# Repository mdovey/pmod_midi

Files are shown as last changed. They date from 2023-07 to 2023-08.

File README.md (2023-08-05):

# pmod_midi
#### PMOD Adapter for the CME Widi Core BLE MIDI module

 

Kicad files for a PCB adapter board/shield to allow the [CME Widi Core module](https://www.cme-pro.com/widi-core/) to be connected to development boards which use the [Digilent PMOD connector](https://digilent.com/shop/about-system-boards-and-components/).

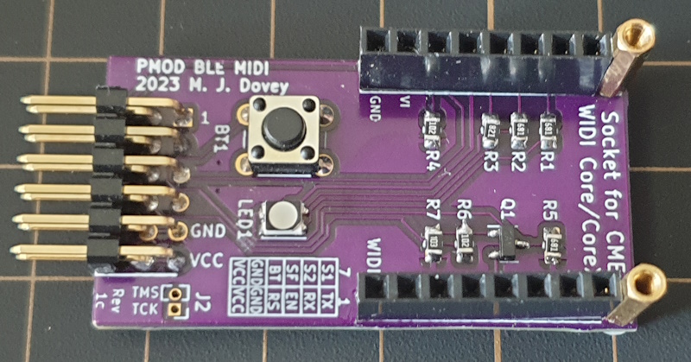
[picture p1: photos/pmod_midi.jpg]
PMOD_MIDI Photograph


| PMOD Pin | Core Pin | Notes |
| --- | --- | --- |
| 1 | 1 (TX) | Connects directly to Widi Core TX pin for MIDI over UART |
| 2 | 11 (RX)  | Connects directly to Widi Core RX pin for MIDI over UART |
| 3 | 6 (ON) | Connects to Widi Core ON pin via pull down resistor. Active high to enable the Widi Core module. |
| 4 | 12 (RS)  | Connects to Widi Core RS pin. Active low reset. |
| 7 | 16 (S1)  | Connects to Widi Core S1 pin. Bluetooth connection status (0 = Not connected, 1 = Connected). |
| 8 | 15 (S2)  | Connects to Widi Core C2 pin. Bluetooth role (0 = peripheral, 1 = central) |
| 9 | 13 (SF)  | Connects to Widi Core SF pin. Baud rate (0 = 31.25 Kb/s, 1 = 100 Kb/s). Requires reset cycle to execute change. |
| 10 | 14 (BT)  | If 1, shorts Widi Core BT pin to ground - simulating button press. |

The board also has a push button which shorts Widi Core pin 14 (BT) to ground (for factory reset and bluetooth role change), and an RGB LED, powered by Widi Core pins 2 (LB), 3(LG), 4 (LR) and 5(V3), for status information (see [CME Widi Core datasheet](https://www.cme-pro.com/wp-content/uploads/2022/10/widiCore-Doc-v1.3.pdf), page 9). An optional 0.5 inch pitch header can provide access to the Widi Core pins 9 (TMS) and 10 (TCK)

The [BOM](./kicad/pmod_midi_bom.md) includes sockets to allow the CME Widi Core (or the Core N/XN with suitable headers) to be inserted and removed. Alternatively the Core N/XN can be hard soldered for example using 0.1 inch pitch header pins.

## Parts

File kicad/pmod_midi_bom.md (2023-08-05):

# pmod_midi.kicad_sch BOM

05/08/2023 12:28:57

Generated from schematic by Eeschema 7.0.6

**Component Count:** 20

| Refs | Qty | Component | Description | Manufacturer | MPN | Notes |
| ----- | --- | ---- | --- | ---- | ---- | ---- |
| BT1 | 1 | SW_Push | Push button switch, generic, two pins | CUI | [TS02-66-60-BK-160-LCR-D](https://www.mouser.co.uk/datasheet/2/670/ts02-2586188.pdf) | 6mm momentarily closed tactile button switch |
| H1, H2 | 2 | MountingHole_Pad | Mounting Hole with connection | Würth Elektronik | [970100244](https://www.we-online.com/components/products/datasheet/970100244.pdf) | Optional: 10mm M2 female to female standoff spacer,  |
| J1 | 1 | PMOD (12 Pin) | Digilent 12 Pin PMOD Connector | Samtec | [TSW-106-08-L-D-RA](https://suddendocs.samtec.com/catalog_english/tsw_th.pdf) | 2x6 0.1 Inch pitch right-angle pin header |
| J2 | 1 | Conn_01x02_Pin | Generic connector, single row, 01x02, script generated | Mill-Max | [852-10-002-10-001000](https://www.mill-max.com/catalog/download/2017-11:034.pdf) | Optional: 1x2 0.05 Inch pitch pin header |
| J3 | 1 | CME_Widi_Core_1-8 | CME Widi Core - Pins 1 - 8 | Samtec | [SSW-108-01-L-S](https://suddendocs.samtec.com/catalog_english/ssw_th.pdf) | 1x8 0.1 Inch pitch pin header socket; . For insertion of pins 1-8 of [CME Widi Core module](https://www.cme-pro.com/wp-content/uploads/2022/10/widiCore-Doc-v1.3.pdf). |
| J4 | 1 | CME_Widi_Core_9-16 | CME Widi Core - Pins 9 - 16 | Samtec | [SSW-108-01-L-S](https://suddendocs.samtec.com/catalog_english/ssw_th.pdf) | 1x8 0.1 Inch pitch pin header socket; . For insertion of pins 9-16 of [CME Widi Core module](https://www.cme-pro.com/wp-content/uploads/2022/10/widiCore-Doc-v1.3.pdf). |
| LED1 | 1 | LED_ABRG | RGB LED, anode/blue/red/green | Würth Elektronik | [150141M173100](https://www.we-online.com/components/products/datasheet/150141M173100.pdf) | 3528 SMD Common Anode RGB LED (Parity Pin 1 - Red Cathode) |
| Q1 | 1 | Q_NPN_BCE | NPN transistor, base/collector/emitter | STMicroelectronics | [2STR2160](https://www.st.com/resource/en/datasheet/2str2160.pdf) | SOT-23 3 SMD NPN Transistor (Pin order: BCE) |
| R1, R2, R5 | 3 | 680 | Resistor |  | 680 ohm 0805 SMD Resistor |  |
| R3 | 1 | 820 | Resistor |  | 820 ohm 0805 SMD Resistor |  |
| R4, R6 | 2 | 1k | Resistor |  | 1k ohm 0805 SMD Resistor |  |
| R7 | 1 | 10k | Resistor |  | 10k ohm 0805 SMD Resistor |  |
| U1–4 | 4 | M2 Nylon Machine Screw | Machine Screw | Essentra | [50M020040D004](https://www.essentracomponents.com/en-us/p/nylon-cheese-head-screws/50m020040d004) | Optional: M2 4mm nylon pan head machine screw |

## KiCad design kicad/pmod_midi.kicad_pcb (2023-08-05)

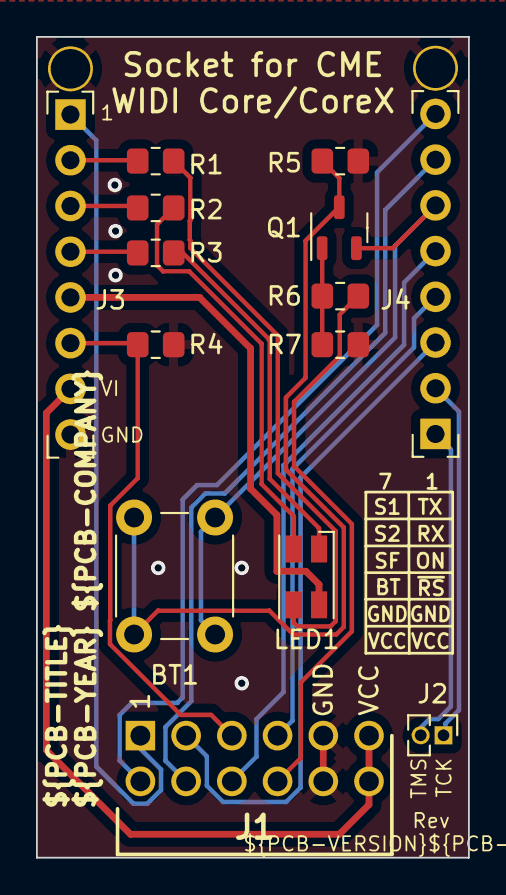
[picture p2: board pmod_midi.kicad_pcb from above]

Board: 2 copper layers, 24.0 x 45.6 mm, 16 parts (0 on the bottom side), 22 nets.

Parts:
BT1: SW_Push; SW_PUSH_6mm
H1, H2: MountingHole_Pad; Standoff Spacer
J1: PMOD (12 Pin)
J2: Conn_01x02_Pin; PinHeader_1x02_P1.27mm_Vertical
J3: CME_Widi_Core_1-8; CME Widi Core Socket Pins 1 - 8
J4: CME_Widi_Core_9-16; CME Widi Core Socket Pins 9 - 16
LED1: LED_ABRG; LED_RGB_Wuerth-PLCC4_3.2x2.8mm_150141M173100
Q1: Q_NPN_BCE; SOT-23-3
R1, R2, R5: 680; R_0805_2012Metric_Pad1.20x1.40mm_HandSolder
R3: 820; R_0805_2012Metric_Pad1.20x1.40mm_HandSolder
R4, R6: 1k; R_0805_2012Metric_Pad1.20x1.40mm_HandSolder
R7: 10k; R_0805_2012Metric_Pad1.20x1.40mm_HandSolder

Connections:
/3.3V: J1.6 (VCC), J1.12 (VCC), J3.7 (VI)
/BLUE: LED1.2 (BK), R1.1
/BT: J1.10, R6.2
/BT*: Q1.1 (B), R6.1, R7.1
/GND: H1.1, H2.1, J1.5 (GND), J1.11 (GND), J3.8 (GND), R4.1, R5.1, R7.2
/GND*: BT1.2, Q1.3 (E), R5.2
/GREEN: LED1.4 (GK), R2.1
/LB: J3.2 (LB), R1.2
/LG: J3.3 (LG), R2.2
/LR: J3.4 (LR), R3.2
/ON: J1.3, J3.6 (ON), R4.2
/RED: LED1.3 (RK), R3.1
/RX: J1.2, J4.11 (RX)
/S1: J1.7, J4.16 (S1)
/S2: J1.8, J4.15 (S2)
/SF: J1.9, J4.13 (SF)
/TCK: J2.1 (TCK), J4.10 (TCK)
/TMS: J2.2 (TMS), J4.9 (TMS)
/TX: J1.1, J3.1 (TX)
/V3: J3.5 (V3), LED1.1 (A)
/~BT: BT1.1, J4.14 (~BT), Q1.2 (C)
/~RS: J1.4, J4.12 (~RS)

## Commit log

2023-07-26 Initial PCB layout
    [pmod_midi.kicad_pcb, pmod_midi.kicad_sch]
2023-07-26 Tidied footprints
    [pmod_midi.kicad_pcb]
2023-07-27 Added BOM
    [pmod_midi.kicad_pcb, pmod_midi.kicad_sch]
2023-08-01 Updated BOM
    [pmod_midi.kicad_pcb, pmod_midi.kicad_sch]

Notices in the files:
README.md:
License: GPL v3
